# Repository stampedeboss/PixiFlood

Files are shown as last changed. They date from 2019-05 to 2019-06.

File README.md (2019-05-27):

# PixiFlood
PixiFlood LED Driver, Turn a 10w-100w floodlight Housing into a WS2811 Floodlight Pixel

DESCRIPTION:

A LED Driver that will allow a flood light to be controlled as a WS2811 Pixel. Allows up to 
170 flood lights to be controlled with a single universe. 

My goal was to enable placement of a flood light without having to deal with different controllers or 
wiring needs. By using WS2811, place a flood light at the beginning or end of a pixel string and maintain 
complete control. 

Version 2 and Version 3 introduced the concept of a built in ESPixelStick, which allows wireless connectitivy to communicate with the Floodlight.

Version 3:
Focused on delivering a single board designed to support any wattage of LED from 10w to 100w.
This objective required the design to no longer include direct attachment of the LED to the PCB, it is to 
be connected via wires to allow for the wide arrangement of LED sizes and pin spacings.

The previous designs relied on linear voltage regulators since the voltage reduction was acceptable going 
from 12v to 5v.  With the use of higher wattage LEDs, voltage requirements are much greater required changing
the 5v voltage regulator circuitry to a switching model to eliminate the overheating of the previous design.

The PT4115 specifications are unacceptable to anything above a 20w LED, as such beginning with 3.0 the LED
Driver is being switched out for an AL8862 and the supporting components have been modified to support that
new IC.

This new design includes the addition of a sidecar that contains ESPixelStick capabilities.  Using the sidecar
and an ESP-01 the floodlight can be driven wirelessly.

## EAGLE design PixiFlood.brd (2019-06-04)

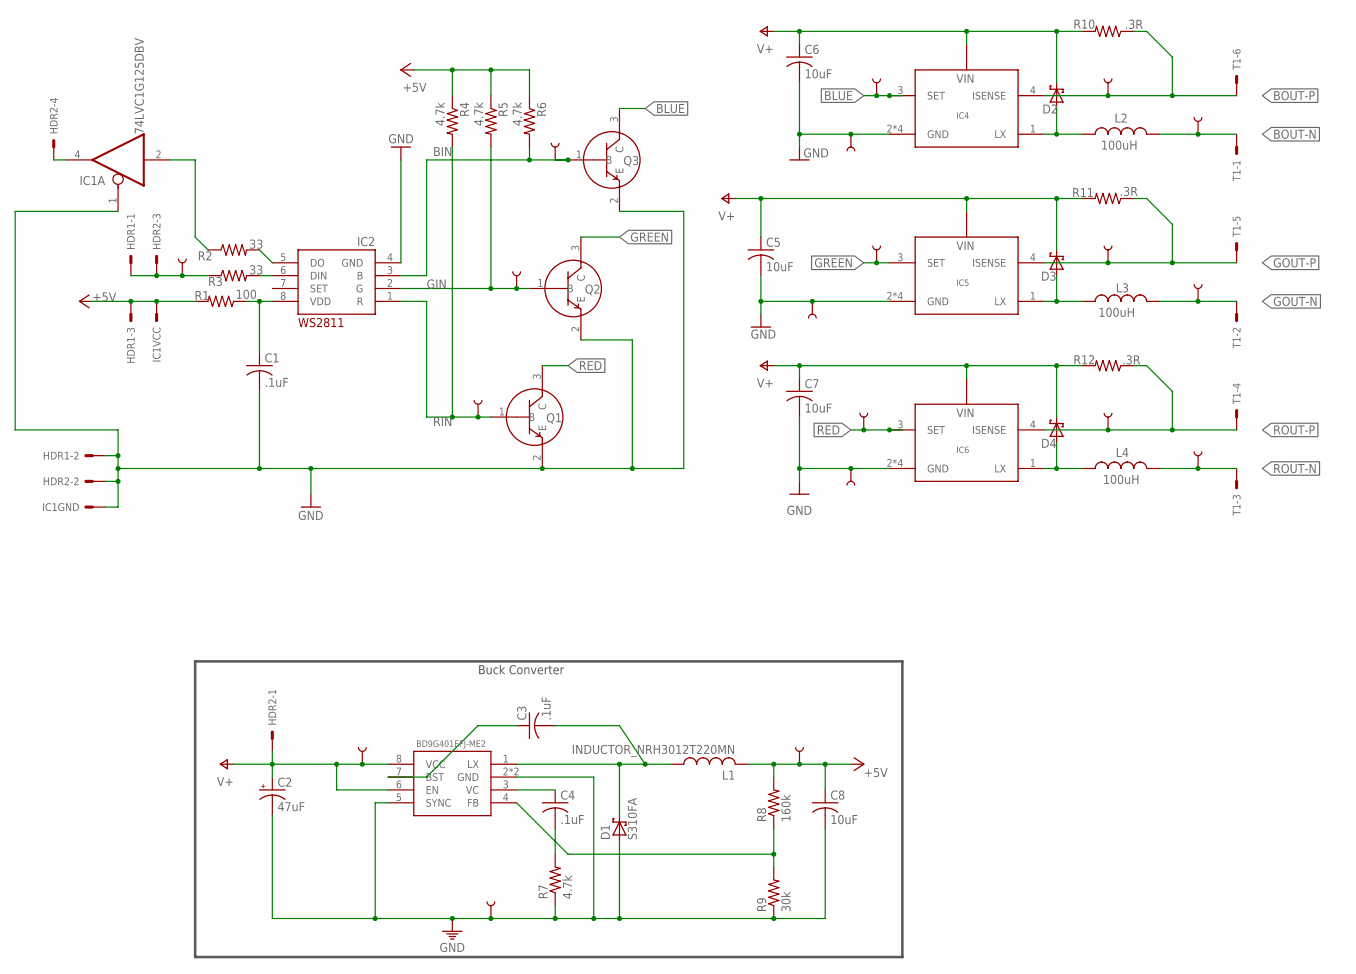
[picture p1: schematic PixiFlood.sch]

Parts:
C1, C3, C4: .1uF; C0805
C2: 47uF; UD-6,3X7,7_NICHICON
C5, C6, C7, C8: 10uF; C1206
D1, D2, D3, D4: S310FA; SOD-123FL
HDR1: M03FEMALE; 1X03_FEMALE
HDR2: M04STD; 1X04
IC1: 74LVC1G125DBV; SOT23-5
IC2: WS2811SOP8; SO08-P-1.27
IC3: BD9G401EFJ-ME2; SOIC127P600X100-9N
IC4, IC5, IC6: AL-8861SOT89-5; SOT89-5
L1: INDUCTOR_NRH3012T220MN; IND_TAIYO_NRH3012
L2, L3, L4: 100uH; SLF7045
Q1, Q2, Q3: BC847BC847; SOT23-3
R1: 100; R0805
R2, R3: 33; R0805
R4, R5, R6, R7: 4.7k; R0805
R8: 160k; R0805
R9: 30k; R0805
R10, R11, R12: .3R; R1210
T1: M06SIP; 1X06
TP1: ROUT-N; TP-1
TP2: GOUT-N; TP-1
TP3: BOUT-N; TP-1
TP4: RED; TP-1
TP5: BLUE; TP-1
TP6: GREEN; TP-1
TP7: BOUT-P; TP-1
TP8: GOUT-P; TP-1
TP9: ROUT-R; TP-1
TP11: RIN; TP-1
TP12: VIN; TP-1
TP13: DIN; TP-1
TP14, TP19, TP20, TP23: GND; TP-1
TP15: 5V; TP-1
TP21: BIN; TP-1
TP22: GIN; TP-1

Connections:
+5V: C8.1, HDR1.5, IC1.5 (S), L1.2, R1.2, R4.1, R5.1, R6.1, R8.2, TP15.P$1
BIN: IC2.3 (B), Q3.1 (B), R6.2, TP21.P$1
BLUE: IC4.3 (SET), Q3.3 (C), TP5.P$1
BOUT-N: L2.2, T1.1, TP3.P$1
BOUT-P: IC4.4 (ISENSE), R10.1, T1.6, TP7.P$1
DIN-IN: HDR1.1, HDR2.3, R3.1, TP13.P$1
DO: HDR2.4, IC1.4 (O)
GIN: IC2.2 (G), Q2.1 (B), R5.2, TP22.P$1
GND: C1.2, C2.-, C5.2, C6.2, C7.2, C8.2, D1.A, HDR1.3, HDR2.2, IC1.1 (OE), IC1.3 (S), IC2.4 (GND), IC3.2 (GND), IC3.5 (SYNC), IC3.9 (GND), IC4.2 (GND), IC4.2@1 (GND), IC4.2@2 (GND), IC4.2@3 (GND), IC5.2 (GND), IC5.2@1 (GND), IC5.2@2 (GND), IC5.2@3 (GND), IC6.2 (GND), IC6.2@1 (GND), IC6.2@2 (GND), IC6.2@3 (GND), Q1.2 (E), Q2.2 (E), Q3.2 (E), R7.1, R9.1, TP14.P$1, TP19.P$1, TP20.P$1, TP23.P$1
GOUT-N: L3.2, T1.2, TP2.P$1
GOUT-P: IC5.4 (ISENSE), R11.1, T1.5, TP8.P$1
GREEN: IC5.3 (SET), Q2.3 (C), TP6.P$1
unnamed: C4.1, IC3.3 (VC)
unnamed: D4.A, IC6.1 (LX), L4.1
unnamed: C3.2, D1.C, IC3.1 (LX), L1.1
unnamed: IC1.2 (I), R2.1
unnamed: D3.A, IC5.1 (LX), L3.1
unnamed: IC2.5 (DO), R2.2
unnamed: IC2.6 (DIN), R3.2
unnamed: C4.2, R7.2
unnamed: D2.A, IC4.1 (LX), L2.1
unnamed: IC3.4 (FB), R8.1, R9.2
unnamed: C3.1, IC3.7 (BST)
RED: IC6.3 (SET), Q1.3 (C), TP4.P$1
RIN: IC2.1 (R), Q1.1 (B), R4.2, TP11.P$1
ROUT-N: L4.2, T1.3, TP1.P$1
ROUT-P: IC6.4 (ISENSE), R12.1, T1.4, TP9.P$1
V+: C2.+, C5.1, C6.1, C7.1, D2.C, D3.C, D4.C, HDR2.1, IC3.6 (EN), IC3.8 (VCC), IC4.5 (VIN), IC5.5 (VIN), IC6.5 (VIN), R10.2, R11.2, R12.2, TP12.P$1
VDD: C1.1, IC2.8 (VDD), R1.1

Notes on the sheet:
Buck Converter

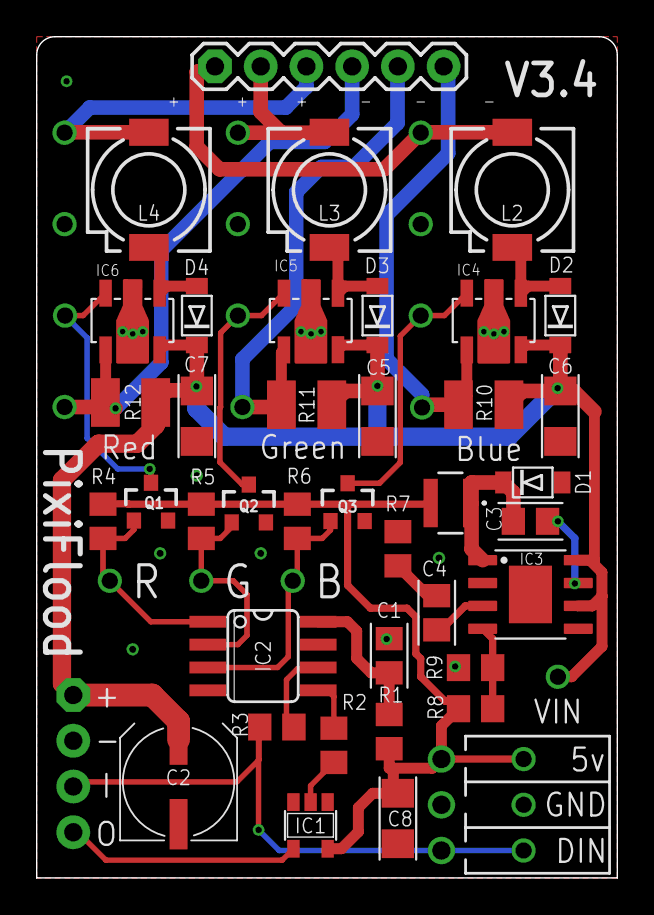
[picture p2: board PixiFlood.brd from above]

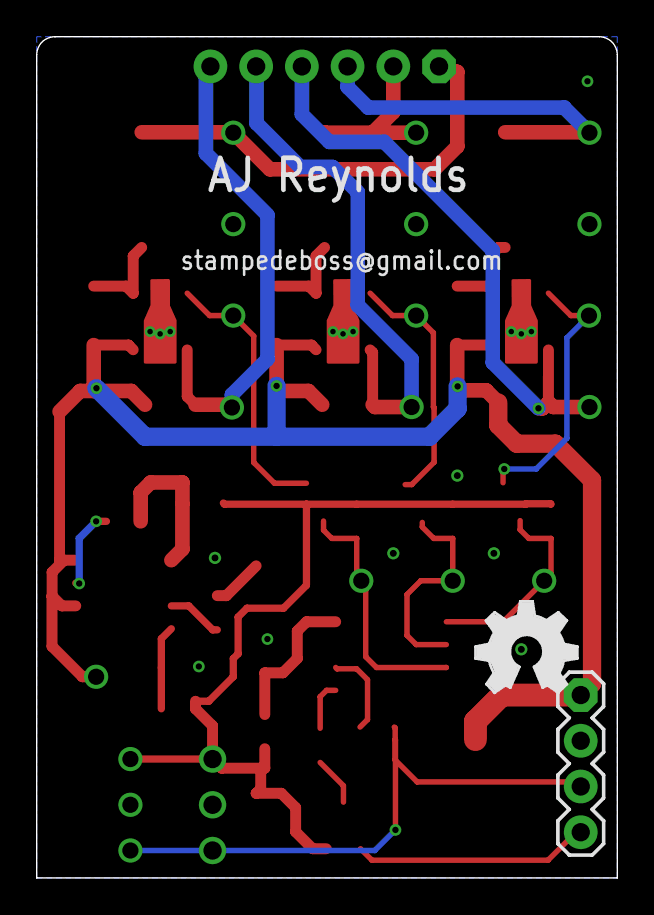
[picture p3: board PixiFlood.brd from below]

Board: 2 copper layers, 32.3 x 46.7 mm, 60 parts (2 on the bottom side), 29 nets.

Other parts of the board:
LOGO: OSHW_FILLX200_NOTEXT

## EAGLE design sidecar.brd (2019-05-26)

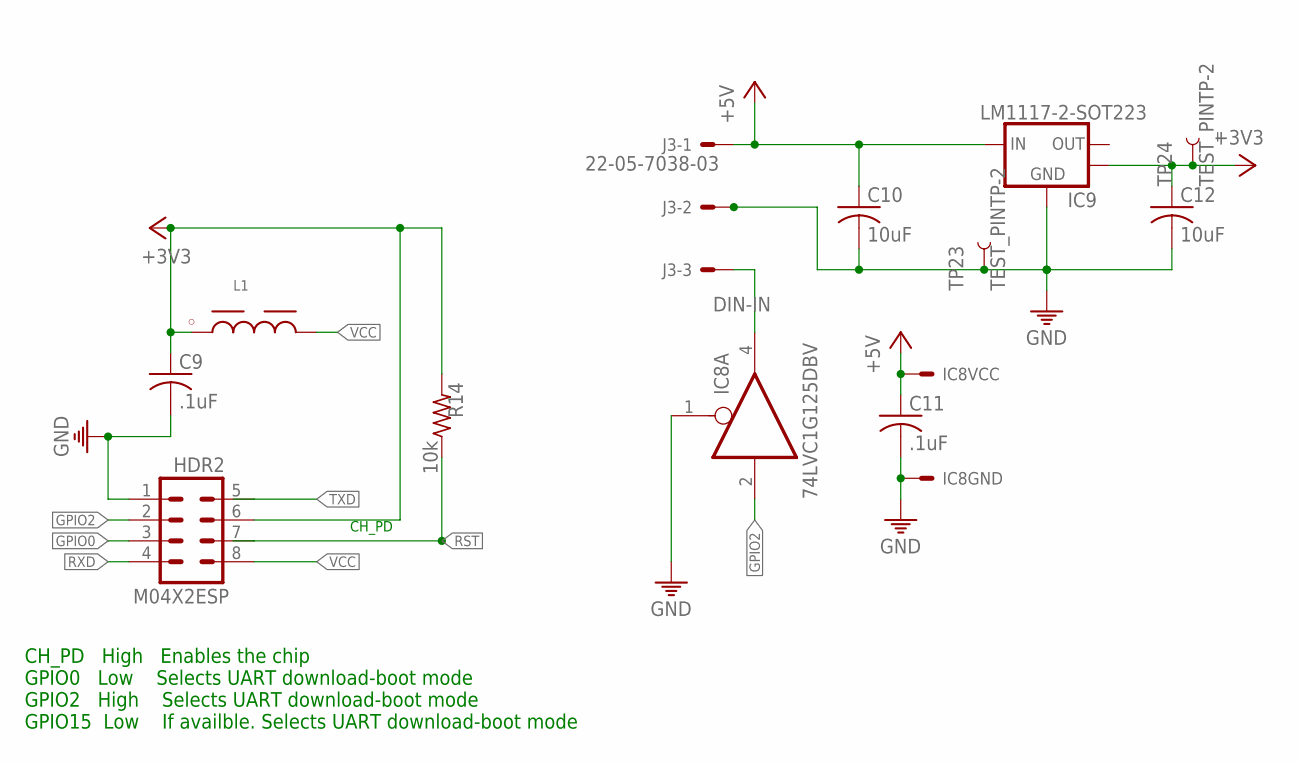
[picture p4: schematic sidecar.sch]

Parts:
C9, C11: .1uF; C0805
C10, C12: 10uF; C0805
HDR2: M04X2ESP; 2X4-ESP
IC8: 74LVC1G125DBV; SOT23-5
IC9: LM1117-2-SOT223; SOT-223-3
J3: 22-05-7038-03; 7395-03
L1: WE-CBA_0805_782851102_WB/HS; WE-CBA_0805(W=3)
R14: 10k; R0805
TP23, TP24: TEST_PINTP-2; TP-2

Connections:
+3V3: C9.1, C12.1, HDR2.6, IC9.4 (HEATSINK), L1.1, R14.2, TP24.P$1
+5V: C10.1, C11.1, IC8.5 (S), IC9.3 (VIN), J3.1
DIN-IN: IC8.4 (O), J3.3
GND: C9.2, C10.2, C11.2, C12.2, HDR2.1, IC8.1 (OE), IC8.3 (S), IC9.1 (GND), J3.2, TP23.P$1
GPIO0: HDR2.3
GPIO2: HDR2.2, IC8.2 (I)
RST: HDR2.7, R14.1
RXD: HDR2.4
TXD: HDR2.5
VCC: HDR2.8, L1.2

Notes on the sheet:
CH_PD High Enables the chip GPIO0 Low Selects UART download-boot mode GPIO2 High Selects UART download-boot mode GPIO15 Low If availble. Selects UART download-boot mode
CH_PD

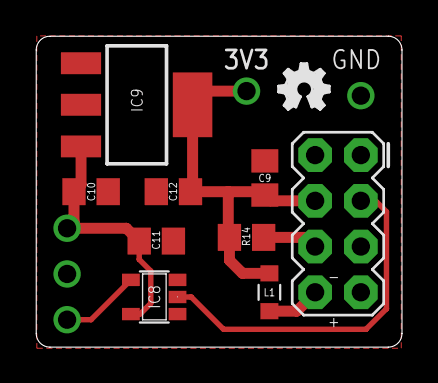
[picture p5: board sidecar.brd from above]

Board: 2 copper layers, 20.3 x 17.3 mm, 13 parts (1 on the bottom side), 7 nets.

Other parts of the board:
U$8: OSHW_FILLX100_NOTEXT

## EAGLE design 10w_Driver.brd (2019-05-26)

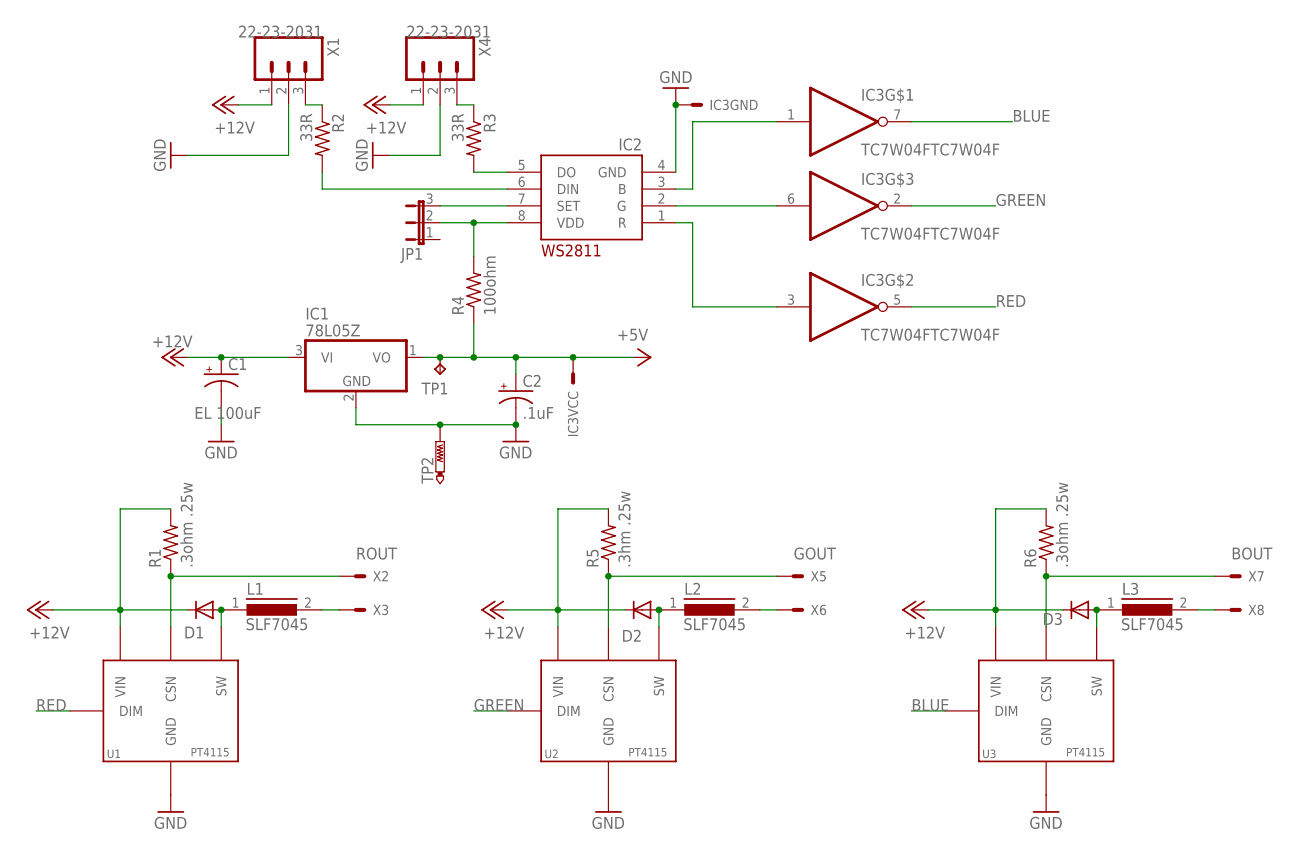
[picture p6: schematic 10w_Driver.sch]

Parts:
C1: EL 100uF; TT2D6L
C2: .1uF; B45181A
D1, D2, D3: DIODE-DO07; DO07
IC1: 78L05Z; TO92
IC2: WS2811-SOP8; SO08-SKINNYPADS
IC3: TC7W04FTC7W04F; SO08
JP1: JP2E; JP2
L1, L2, L3: SLF7045
R1, R6: .3ohm .25w; R1206
R2, R3: 33R; M0805
R4: 100ohm; M0805
R5: .3hm .25w; M1206
TP1: TPB2,54; B2,54
TP2: PTR1TP20SQ; TP20SQ
U1, U2, U3: PT4115PT4115B89E; SOT89-5
X1, X4: 22-23-2031
X2, X3, X5, X6, X7, X8: LED-PAD

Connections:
+5V: C2.+, IC1.1 (VO), IC3.8 (S), R4.1, TP1.TP
+12V: C1.+, D1.C, D2.C, D3.C, IC1.3 (VI), R1.2, R5.2, R6.2, U1.5 (VIN), U2.5 (VIN), U3.5 (VIN), X1.1, X4.1
BLUE: IC3.7 (O), U3.3 (DIM)
BOUT: R6.1, U3.4 (CSN), X7.P$1@1, X7.P$1@2, X7.P$1@3
GND: C1.-, C2.-, IC1.2 (GND), IC2.4 (GND), IC3.4 (S), TP2.TP, U1.2 (GND), U1.2A (GND), U1.2A@1 (GND), U1.2A@2 (GND), U1.2A@3 (GND), U1.2A@4 (GND), U2.2 (GND), U2.2A (GND), U2.2A@1 (GND), U2.2A@2 (GND), U2.2A@3 (GND), U2.2A@4 (GND), U3.2 (GND), U3.2A (GND), U3.2A@1 (GND), U3.2A@2 (GND), U3.2A@3 (GND), U3.2A@4 (GND), X1.2, X4.2
GOUT: R5.1, U2.4 (CSN), X5.P$1@1, X5.P$1@2, X5.P$1@3
GREEN: IC3.2 (O), U2.3 (DIM)
unnamed: D1.A, L1.1, U1.1 (SW)
unnamed: D3.A, L3.1, U3.1 (SW)
unnamed: L1.2, X3.P$1@1, X3.P$1@2, X3.P$1@3
unnamed: R3.1, X4.3
unnamed: D2.A, L2.1, U2.1 (SW)
unnamed: R2.1, X1.3
unnamed: IC2.5 (DO), R3.2
unnamed: IC2.6 (DIN), R2.2
unnamed: L2.2, X6.P$1@1, X6.P$1@2, X6.P$1@3
unnamed: L3.2, X8.P$1@1, X8.P$1@2, X8.P$1@3
unnamed: IC2.8 (VDD), JP1.2, R4.2
unnamed: IC2.1 (R), IC3.3 (I)
unnamed: IC2.3 (B), IC3.1 (I)
unnamed: IC2.7 (SET), JP1.3
unnamed: IC2.2 (G), IC3.6 (I)
RED: IC3.5 (O), U1.3 (DIM)
ROUT: R1.1, U1.4 (CSN), X2.P$1@1, X2.P$1@2, X2.P$1@3

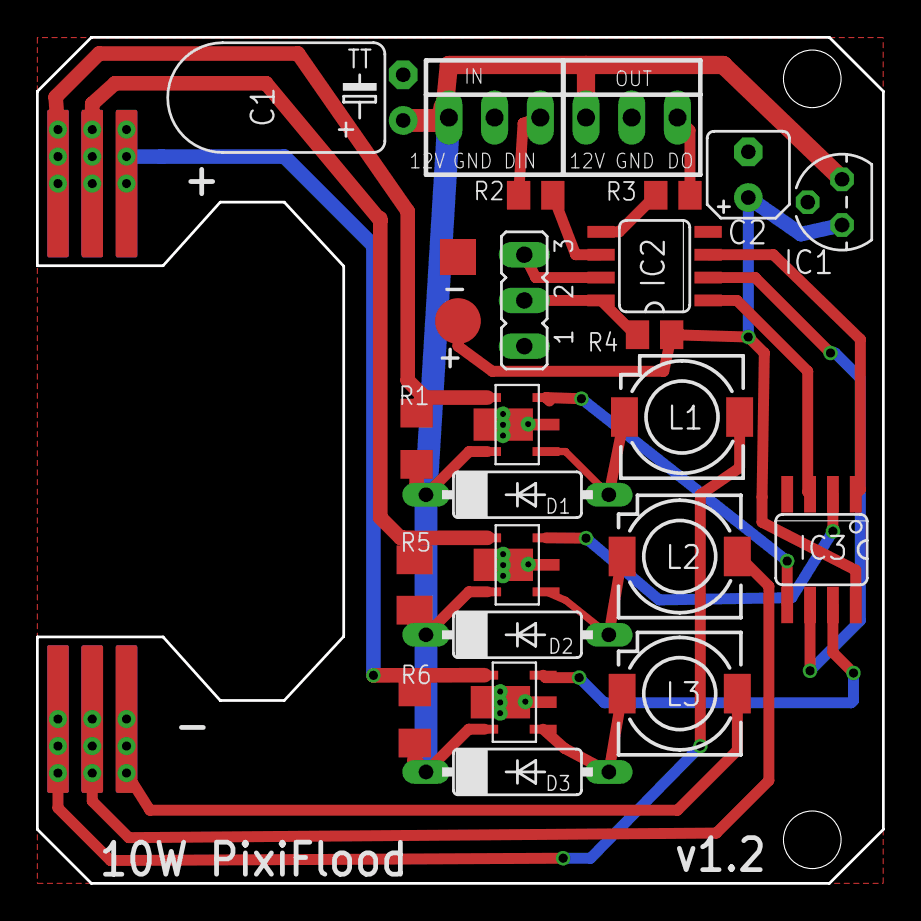
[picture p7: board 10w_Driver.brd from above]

Board: 2 copper layers, 47.0 x 47.0 mm, 31 parts (0 on the bottom side), 24 nets.

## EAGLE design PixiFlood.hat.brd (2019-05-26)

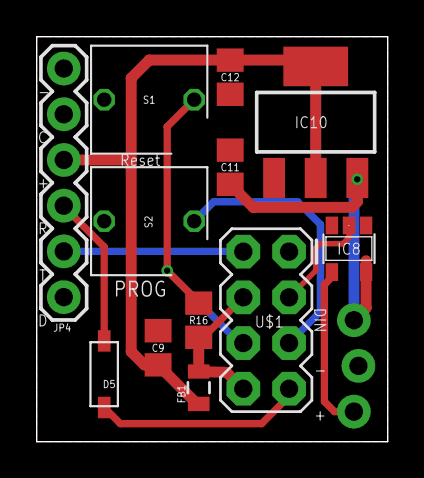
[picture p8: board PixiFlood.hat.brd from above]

Board: 2 copper layers, 19.5 x 22.5 mm, 13 parts (1 on the bottom side), 11 nets.

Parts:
C9, C11, C12: C0805
D5: 1N4148; SOD-123
FB1: FB; 0805
IC8: 74LVC1G125DBV; SOT23-5
IC10: LM1117-2-SOT223; SOT-223-3
JP3: 1X03_LOCK
JP4: 1X06
R16: 10k; R0805
S1, S2: TACT_5MM
U$1: M04X2ESP; 2X4-ESP

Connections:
+3V3: C9.1, C12.1, FB1.1, IC10.2, IC10.4, JP4.3
+5V: C11.1, IC8.5, IC10.3, JP3.1
DIN-IN: IC8.4, JP3.3
GND: C9.2, C11.2, C12.2, IC8.1, IC8.3, IC10.1, JP3.2, JP4.1, S1.2, S2.2, U$1.1
GPIO0: S2.1, U$1.3
GPIO2: IC8.2, U$1.2
unnamed: D5.C, JP4.4
RST: R16.1, S1.1, U$1.7
RXD: D5.A, U$1.4
TXD: JP4.5, U$1.5
VCC: FB1.2, R16.2, U$1.6, U$1.8

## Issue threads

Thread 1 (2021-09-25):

BOM ?

marx1, 2021-09-25:
Do you have a BOM for this PCB? I don't have access to Eagle, so I can't pull up the schematic.

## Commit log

2019-05-26 Initial Design with ws2811
    [10w_Driver.brd, 10w_Driver.sch]
2019-05-26 Final 1.1
    [10w_Driver.brd, 10w_Driver.sch]
2019-05-26 Final 1.1 with Inverter
    [10w_Driver.brd, 10w_Driver.sch]
2019-05-26 Reworked Inverter Layout
    [10w_Driver.brd, 10w_Driver.sch]
2019-05-26 Reworked Layout
    [10w_Driver.brd, 10w_Driver.sch]
2019-05-26 Reworked and retitled to PixiFlood
    [PixiFlood.brd, PixiFlood.sch]
2019-05-26 Reworked and retitled to PixiFlood SMD
    [PixiFlood.brd, PixiFlood.sch]
2019-05-26 Reworking Sidecar
    [PixiFlood.hat.brd]
2019-05-26 Transistor version
    [PixiFlood.csv, sidecar.brd, sidecar.sch]
2019-05-26 Modified testpoint drill size
    [PixiFlood.brd, PixiFlood.sch]
2019-05-26 Panelized Boards
    [PixiFlood.brd, sidecar.brd]
2019-05-30 Cleaned up some labels
    [PixiFlood.brd, PixiFlood.sch]
2019-05-30 Cleaned up transistors
    [PixiFlood.brd, PixiFlood.sch]
2019-06-01 Changed Connector
    [PixiFlood.brd, PixiFlood.sch]
2019-06-04 added adpater boards and changed pinout on led
    [10w_Adapter.brd, 10w_Adapter.sch, 20w_Adapter.brd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]

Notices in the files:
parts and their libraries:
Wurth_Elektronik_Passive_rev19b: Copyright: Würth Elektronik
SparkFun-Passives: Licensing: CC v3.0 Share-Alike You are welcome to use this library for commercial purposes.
